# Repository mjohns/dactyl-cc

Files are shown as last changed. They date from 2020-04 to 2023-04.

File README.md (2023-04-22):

# Dactyl CC Keyboard

This keyboard and associated libraries take heavy inspiration from the
 [dactyl](https://github.com/adereth/dactyl-keyboard) and
the [dactyl_manuform](https://github.com/abstracthat/dactyl-manuform) keyboards.
 Major thanks to Matthew Adereth and Tom Short for their work.

The dactyl-cc keyboard takes a different approach to the structure of the code (and language)
 as well as being more similar in feel to the Kinesis Advantage 2.

If you are interested in a smaller version see the [mini](https://github.com/mjohns/dactyl-cc-mini) version.

If you are interested in building it you can take a look at the [guide](guide/README.md). Any dactyl build guide you choose should work like [this one.](https://medium.com/swlh/complete-idiot-guide-for-building-a-dactyl-manuform-keyboard-53454845b065)



CMake is the preferred way to build and leads to the fastest recompilation times.
```
cd build
./build.sh
```

If you do not have cmake installed you can run the simple build script which just uses g++.
```
cd build
./build_simple.sh
```

You can generate an stl from the command line with the following command:
```
cd build
// openscad -o ../things/left.stl left.scad
make_things.sh
```

The external holder cutout design is taken from https://github.com/cykedev/dactyl-cc and is designed to for loligagger's external holder.

Loligagger's external holder files:

* [Promicro V1](https://web.archive.org/web/20220607031919/https://dactyl.siskam.link/loligagger-external-holder-promicro-v1.stl)
* [Promicro V2](https://web.archive.org/web/20220607031910/https://dactyl.siskam.link/loligagger-external-holder-promicro-v2.stl)
* [Elite-C V1](https://web.archive.org/web/20220607031927/https://dactyl.siskam.link/loligagger-external-holder-elite-c-v1.stl)

v2 changes:
* Smoothed out back walls and walls around thumb cluster.
* Merged https://github.com/cykedev/dactyl-cc for external holder.
* Adjusted 'g' colum rotation from 10 to 4 degrees.

v1 stl files are archived in the things folder. The source code can be viewed on the v1 git branch.





[other images](https://imgur.com/a/jBbUXNx)

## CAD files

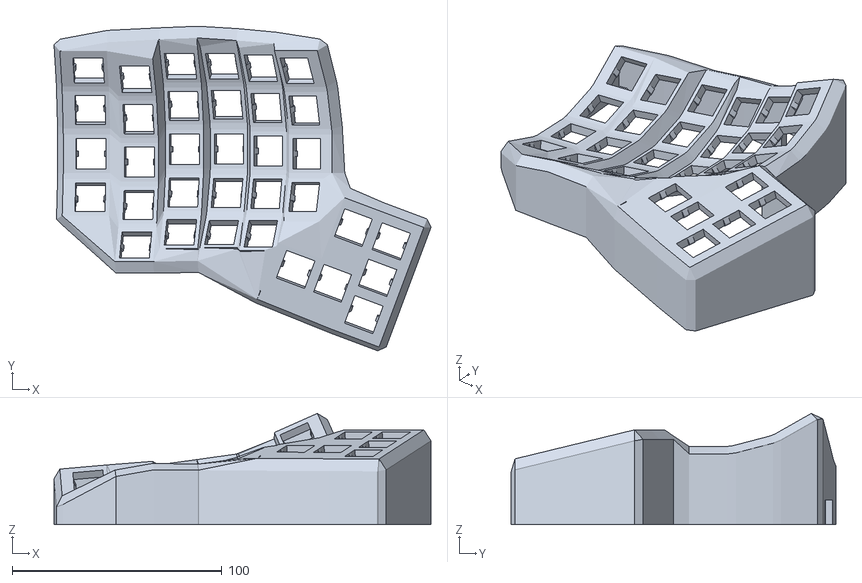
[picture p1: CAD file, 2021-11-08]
things/left.stl
179.7 x 154.7 x 53.0

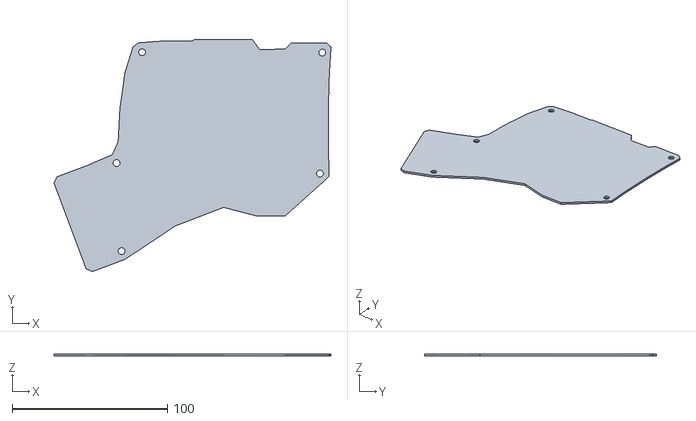
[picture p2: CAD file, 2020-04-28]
things/v1/v1_bottom_right.stl
178.4 x 149.5 x 1.50

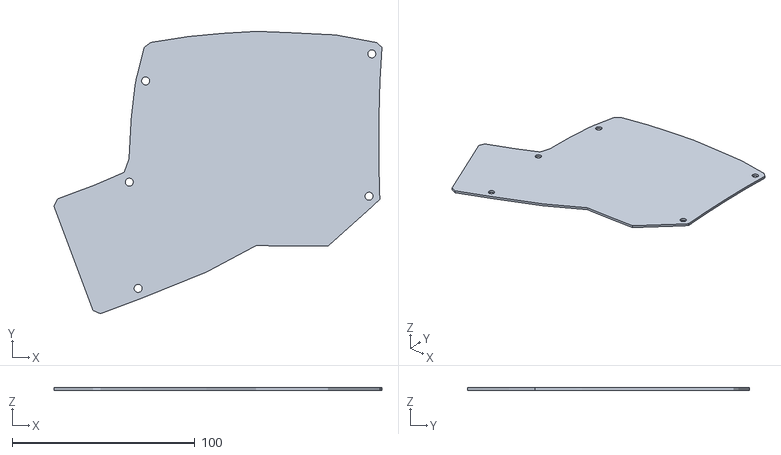
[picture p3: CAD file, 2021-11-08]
things/bottom_right.stl
179.7 x 154.7 x 1.50

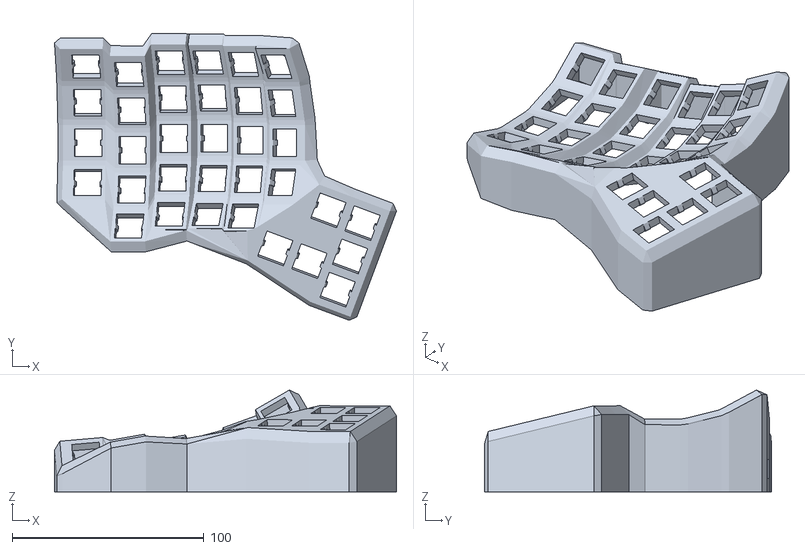
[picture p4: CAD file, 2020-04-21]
things/v1/v1_left.stl
178.4 x 149.5 x 53.2

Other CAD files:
things/v1/v1_bottom_left.stl
things/bottom_left.stl
things/right.stl
things/v1/v1_right.stl

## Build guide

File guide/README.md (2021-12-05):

I built this keyboard following the [Dactyl QMK Guide](https://www.joedevivo.com/2017-05-20-building-a-qmk-dactyl) by Joe Devivo.
 This is how I have built all of my Dactyl keyboards and allows me to build the firmware
 using the ErgodoxEZ online configurator which is now branded as [oryx](https://configure.ergodox-ez.com/).
The guide can also be found directly in the [dactyl github repo](https://github.com/adereth/dactyl-keyboard/tree/master/qmk-guide).

This keyboard does not have as much room around the keys in the corners and edges so it can be challenging to solder them.
I would suggest being mindful of what your soldering iron is touching because it is very easy to lose track and start
melting the side of the case (from personal experience). You can also solder on the diode and a stretch of wire before putting
the switch in but that turned out to be more trouble than it was worth.

The most important parts of the guide are the following two images which you will refer to quite often:
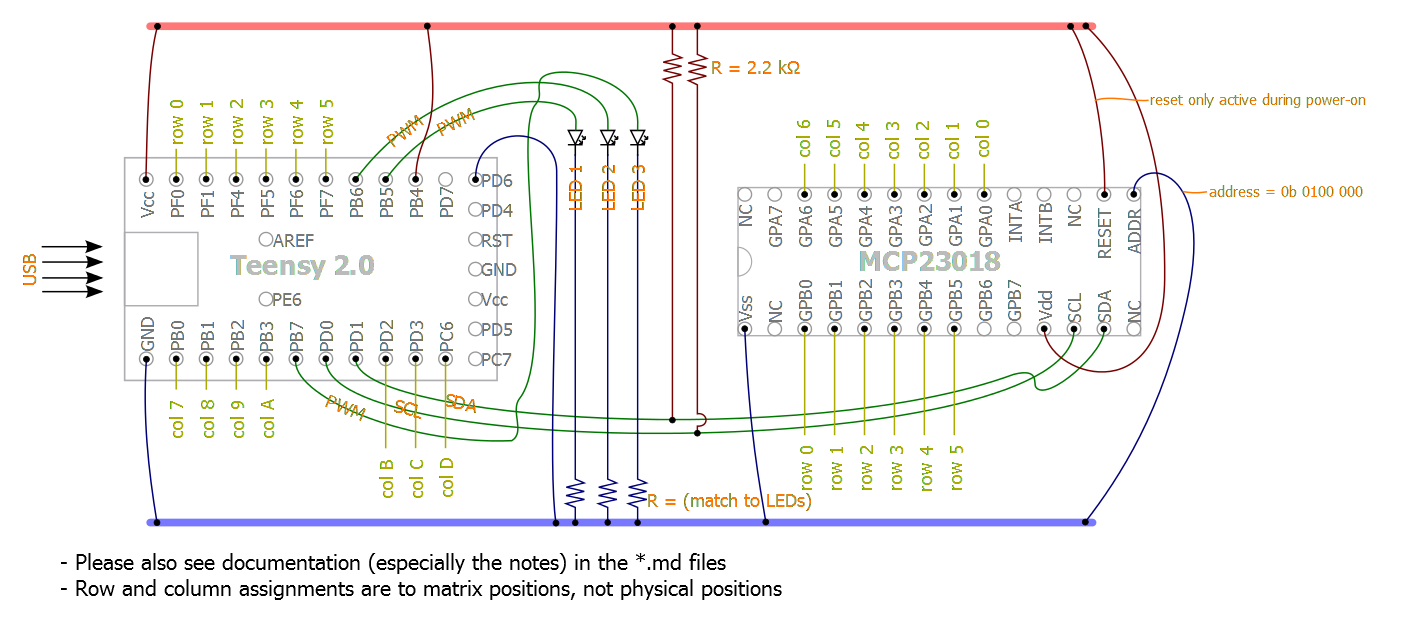
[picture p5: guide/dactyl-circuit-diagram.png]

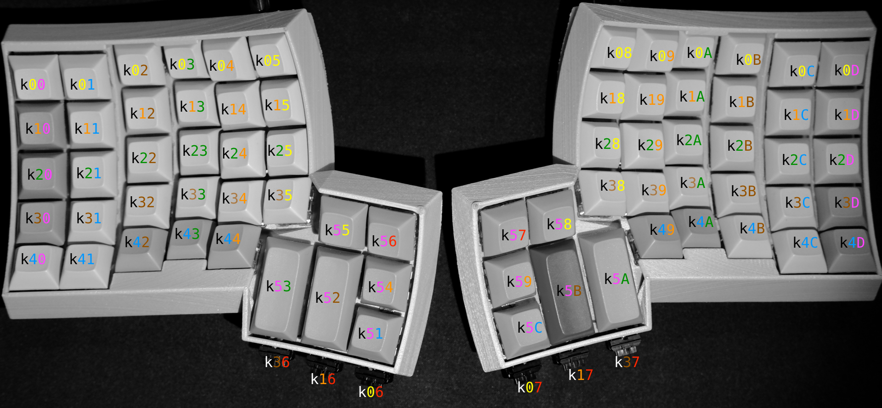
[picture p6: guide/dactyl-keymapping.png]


I think Amoeba PCBs should fit but it is a close call. I was able to get one in the tightest corner but you have to angle it very carefully to get it over the pins.



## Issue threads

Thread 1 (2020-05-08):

Bill of materials

lucasuyezu, 2020-05-08:
Congrats on the project, this is awesome!

Could you add the Bill of Materials to the README?

Thanks!

mjohns, 2020-05-09:
I added a link to the guide from the main readme. I just followed the qmk guide from the dactyl repo. https://github.com/adereth/dactyl-keyboard/tree/master/qmk-guide. I don't have a real bill or materials as a lot of the parts were left over from a dactyl build from a few years ago.

That guide has a pretty good section about the materials that you would need. If you don't want to use a Teensy (and want to use pro micros) you could look at this guide https://nickgreen.info/dactyl-manuform-build-log/.

Closed 2020-05-09.

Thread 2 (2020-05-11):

Enough space for Amoebas?

simonjohansson, 2020-05-11:
Howdie. Cool alternative to the Dactyl!

You mention in the guide,

```
This keyboard does not have as much room around the keys in the corners and edges
```

Do you think it has enough space for [Amoebas](https://keeb.io/collections/frontpage/products/amoeba-single-switch-pcbs?variant=12960782024798)?

mjohns, 2020-05-12:
I updated the guide with an image of one in the tightest corner. It fits but I don't have any experience with them to say if that is enough. See https://github.com/mjohns/dactyl-cc/tree/master/guide

simonjohansson, 2020-05-14:
Thanks!

Closed 2020-05-12.

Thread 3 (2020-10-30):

Case material

ntarocco, 2020-10-30:
Hi, thanks a lot for this repo! I am about to build my keyboard as yours! I love it.

I am still not convinced which material to use to 3d print the case. I am worried about the finishing look&feel.
Which one did you use? Are you happy with robustness and look&feel?

Maybe, it would be great to add some details about your build:
* Material: ABS, PLA or PEGT?
* Infill: 20%?
*. nice to have: any recommendation on which 3d print website to use, if you have any experience?

Thanks!

20lives, 2020-10-30:
I didn't print this variation but I have printed countless others.
Mainly the material will affect only the sturdiness of it, so any material could come out great.
Infill is also partially irrelevant since the walls are really thin.
What makes the biggest difference is the: material quality, printer quality, printer calibration, printing speed.
Moreover, there is a lot of post-processing that can be done to improve "look&feel": sanding, finishing, coating.

The best suggestion I can make is if you have the time: buy your own 3d printer and do it yourself.

mjohns, 2020-11-02:
I have printed all of my keyboards using PLA and the default Cura Ender3 profile (infill 20%). Using tree supports does save a fair bit of time and has worked well for me. I primed and spray painted (https://imgur.com/a/LsxRFcR) the keyboard which really improves the finish and I have had no problems with they keyboards over the past few years.

I printed them myself so I can't recommend any site for that.

ntarocco, 2020-11-02:
Thanks a lot for your answers! I really don't want to buy a 3d printer right now and I don't have access to any.
I have ordered online the case printed with PLA, infill 20%, black.
I was also planning to do some finishing and painting, I will post pictures when ready!

Closed 2021-11-08.

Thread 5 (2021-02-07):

Regarding similarity to Kinesis

mseflek, 2021-02-07:
Hi, Thanks for putting this together. As a long time Kinesis user I think this will solve a lot of problems I am having. Couple of quick questions:

1. Have you designed/use wrist rests with this?
2. Is the thumb cluster at the same height as it is on the Kinesis, or is it slight lower?
3. If you've used both, do you have a clear preference for this vs. the Kinesis?
4. Lastly: I noticed you reused the 1.25u keys on the pinky. Is it easy to make these 1U instead?

hasufell, 2021-06-22:
I'm also concerned about the thumb cluster, since that's one of the maon reasons to look for alternatives (they're too high).

mjohns, 2021-11-08:
1. I used a wrist pad (https://www.amazon.com/Glorious-Gaming-Wrist-Pad-Rest/dp/B0191YRMCO) on top of a 1 inch tall piece of wood. Nothing 3d printed / integrated.
2. The thumb cluster is at the same height relative to the keywell as the kinesis. The whole keyboard is slightly lower than the kinesis.
3. I prefer this over the kinesis because of QMK and the ability to adjust the position of the two keywells independently.
4. You would have to go into key_data.cc and adjust the x offset of key_caps. https://github.com/mjohns/dactyl-cc/blob/master/src/key_data.cc#L183. Changing -22.597 to something around -20.

Closed 2021-11-08.

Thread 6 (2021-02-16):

Manifold issues with the mesh

rubot42, 2021-02-16:
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
I tried editing this in FreeCAD and noticed that the mesh has some manifold errors. Here is a screenshot from Meshmixer pointing out where the errors are.

To reproduce:
- build the models with cmake (same commands as readme)
- convert to a .stl with openscad (same commands as readme)
- import stl into Meshmixer (https://www.meshmixer.com/)

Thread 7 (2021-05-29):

Stabilizers for thumb cluster

daniel2887, 2021-05-29:
Hi,

I was looking for a split keyboard that replicated the keys and layout of the Kinesis Advantage 2 and this fit the bill perfectly, so thank you for sharing your work. I'm in the process of printing it! 🤞

One question about the thumb cluster. I noticed there are no cutouts for stabilizers for the longer (2u?) keys. Did you tack those on somehow after the print? Or did you find they were not needed?

Thanks!

mjohns, 2021-05-31:
I didn't use any stabilizers and it was fine for how I type. The advantage
also doesn't have stabilizers on those thumb keys.

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

daniel2887, 2021-05-31:
Great. Thank you.

Closed 2021-05-31.

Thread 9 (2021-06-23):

Hotswap sockets

Ivche1337, 2021-06-23:
Is it possible to install [these](https://images-na.ssl-images-amazon.com/images/I/51WHrl4VGqL._AC_SX466_.jpg) hotswap sockets in this case?

kaue, 2021-10-01:
Same question :+1:

DuMaM, 2021-11-03:
Those are placed in amoeba pcb board

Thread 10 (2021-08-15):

6x6 its missing ESC and Function buttons

Nurtekin429, 2021-08-15:
I'm used to use Kinesis advantage this had the same thumb buttons.
I think its better for me then manufold.
Its great design what you have done.
I have printed left and right.
Is is possible to make 6x6. Its now missing ESC and Function buttons.
They are very useful.
Thanks in advance.

mjohns, 2021-11-08:
The esc/function keys on the kinesis are pretty different in location and sizing. It would be possible to add another row on top but it would be an involved process as this isn't a parametric layout like with the dactyl manuform. You would need to update key_data.h/cc with the new row of keys and then update the wall generating code to use those new keys instead of the existing top row.

Closed 2021-11-08.

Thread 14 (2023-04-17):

broken links in readme

EPPI-c, 2023-04-17:
links to
[pro micro v1](https://dactyl.siskam.link/loligagger-external-holder-promicro-v1.stl)
[pro micro v2](https://dactyl.siskam.link/loligagger-external-holder-promicro-v2.stl)
[elite-c](https://dactyl.siskam.link/loligagger-external-holder-elite-c-v1.stl)
are broken

Closed 2023-04-22.

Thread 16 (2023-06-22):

3D model filed corrupted

jiahuijiang, 2023-06-22:
I was trying to 3D print the base, but both v1 and v2 models are giving me warnings saying these are corrupted. Can you double check the files are uploaded correctly? Thank you!

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

guategeek, 2023-06-23:
The files are not corrupted on github, I have a copy of the repo I have been going to print from. To double check I just test downloaded the left.stl and threw in in Cura no problem. How did you download the files?

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

jiahuijiang, 2023-06-26:
@guategeek good call!
When I right-clicked on the file name and tried to directly do "save link as", the model files was shown as corrupted. But If I clicked open the file in GitHub UI and then clicked "download", that worked.
Closing this ticket out.

Closed 2023-06-26.

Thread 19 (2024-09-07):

Which keys are being used here, is it MX?

MagedEWilliam, 2024-09-07:
Noob here,
After i printed the model here, i had trouble inserting the key switches, then it dawned on me that i might have printed the wrong model or that i needed to build it with the MX type that i have.

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

My question is which key switch are being used here, and how do i get an STL with the my switch type.

MagidWilliam, 2025-03-10:
@marioolofo i tried to closely match it in cosmos, not 100% match but close enough

https://ryanis.cool/cosmos/beta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

marioolofo, 2025-03-10:
Thanks, I'll try to print this version tonight 😃

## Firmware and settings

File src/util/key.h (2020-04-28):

#pragma once

#include <functional>
#include <glm/glm.hpp>
#include <memory>
#include <string>

#include "scad.h"
#include "transform.h"

namespace scad {

// All sizes in mm.
const double kSwitchWidth = 14.4;
const double kSwitchThickness = 4;
const double kWallWidth = 2;

const double kDsaHeight = 8;
const double kSaHeight = 12.5;
// This is the height of the taller side on the key. The short side has kSaHeight.
const double kSaEdgeHeight = 13.7;
const double kDsaTopSize = 13.2;     // 0.5 * kMmPerInch;
const double kDsaBottomSize = 18.4;  // 0.725 * kMmPerInch;
// The size half way up the key used to generate the cap shape.
const double kDsaHalfSize = 16.2;
const double kSaHalfSize = 17.2;

// Size for the tall sa edged key.
const double kSaTallHeight = 14;
const double kSaTallEdgeHeight = 16.5;

const double kSwitchHorizontalOffset = kSwitchWidth / 2 + kWallWidth;

// This is the distance between the top of the switch plate and the tip of the switch stem.
const double kSwitchTipOffset = 10;

enum class KeyType {
  DSA,
  SA,            // Row 3
  SA_EDGE,       // Row 2
  SA_TALL_EDGE,  // Row 1
};
// For SA edge variants. Which side of the key the edge should be rendered.
enum class SaEdgeType { LEFT, RIGHT, TOP, BOTTOM };

struct Key {
 public:
  Key() {
  }

  Key(double x, double y, double z) {
    t().x = x;
    t().y = y;
    t().z = z;
  }

  // A name for debugging purposes. Can also be used to determine the names for key specific output
  // files.
  std::string name;

  TransformList parent_transforms;
  TransformList local_transforms;

  // These add extra width to the switch and offset the locations of the corners (GetTopLeft etc).
  double extra_width_top = 0;
  double extra_width_bottom = 0;
  double extra_width_left = 0;
  double extra_width_right = 0;

  // This makes the switch taller (moves the corner connectors down and increases wall height) while
  // leaving the top plate of the switch at the same point.
  double extra_z = 0;

  bool add_side_nub = true;
  bool disable_switch_z_offset = false;

  KeyType type = KeyType::DSA;
  SaEdgeType sa_edge_type = SaEdgeType::BOTTOM;

  void Configure(std::function<void(Key& k)> fn) {
    fn(*this);
  }

  Key& SetPosition(double x, double y, double z);
  Key& SetParent(const Key& key);
  Key& SetParent(const TransformList& transforms);

  Transform& t() {
    return local_transforms.mutable_front();
  }

  Transform& AddTransform() {
    return local_transforms.AddTransformFront();
  }

  TransformList GetTransforms() const;
  TransformList GetSwitchTransforms() const;

  Shape GetSwitch() const;
  Shape GetInverseSwitch() const;
  // Used to subtract and clear space in the key cap's path. Vertical length can be explicitly
  // passed to support cutting out for long keys like enter on the kinesis.
  Shape GetInverseCap(double custom_vertical_length = -1) const;
  Shape GetCap(bool fill_in_cap_path = false) const;

  // This is the outermost conner of the switch. You can specify an offset to scale the point back
  // by the specified x,y amount towards the center of the switch. If you had a centered 2x2 post
  // and you wanted the corner to line up with outmost point of the switch, you could specify an
  // offset of -1.
  TransformList GetTopRight(double offset = 0) const;
  TransformList GetTopLeft(double offset = 0) const;
  TransformList GetBottomRight(double offset = 0) const;
  TransformList GetBottomLeft(double offset = 0) const;
  // The same as GetSwitchTransforms but with a more clear name if you are intending to find the
  // middle point.
  TransformList GetMiddle() const;

  // Corners clockwise starting at top left. Will have size 4.
  std::vector<TransformList> GetCorners(double offset = 0) const;

 private:
  // These are the inner corners of the switch plate.
  TransformList GetTopRightInternal() const;
  TransformList GetTopLeftInternal() const;
  TransformList GetBottomRightInternal() const;
  TransformList GetBottomLeftInternal() const;
};

struct KeyGrid {
  explicit KeyGrid(std::vector<std::vector<Key*>> data) : data(std::move(data)) {
  }

  std::vector<Key*> column(int c) {
    std::vector<Key*> result;
    for (auto& row : data) {
      result.push_back(row[c]);
    }
    return result;
  }

  std::vector<Key*> row(int r) {
    return data[r];
  }

  Key* get_key(int row, int column) {
    if (row < 0 || row >= num_rows()) {
      return nullptr;
    }
    auto& r = data[row];
    if (column < 0 || column >= r.size()) {
      return nullptr;
    }
    return r[column];
  }

  std::vector<Key*> keys() {
    std::vector<Key*> result;
    for (auto& row : data) {
      for (Key* key : row) {
        if (key) {
          result.push_back(key);
        }
      }
    }
    return result;
  }

  size_t num_columns() {
    return data[0].size();
  }

  size_t num_rows() {
    return data.size();
  }

  std::vector<std::vector<Key*>> data;
};

// Used to connect key corners together. It is thin so it can have width issues when the two
// connectors being hulled don't have a large projection on one another. (keys close together with
// vertical separation)
Shape GetPostConnector();

Shape ConnectVertical(const Key& top,
                      const Key& bottom,
                      Shape connector = GetPostConnector(),
                      double offset = 0);
Shape ConnectHorizontal(const Key& left,
                        const Key& right,
                        Shape connector = GetPostConnector(),
                        double offset = 0);
Shape ConnectDiagonal(const Key& top_left,
                      const Key& top_right,
                      const Key& bottom_right,
                      const Key& bottom_left,
                      Shape connector = GetPostConnector(),
                      double offset = 0);

Shape Tri(const TransformList& t1,
          const TransformList& t2,
          const TransformList& t3,
          Shape connector = GetPostConnector());
Shape Tri(const Shape& s1, const Shape& s2, const Shape& s3);

Shape TriHull(const TransformList& t1,
              const TransformList& t2,
              const TransformList& t3,
              const TransformList& t4,
              Shape connector = GetPostConnector());
Shape TriHull(const Shape& s1, const Shape& s2, const Shape& s3, const Shape& s4);

Shape TriFan(const TransformList& center,
             const std::vector<TransformList>& transforms,
             Shape connector = GetPostConnector());
Shape TriFan(Shape center, const std::vector<Shape>& shapes);

// Makes a triangle with every consecutive set of 3 transforms. TriHull would be the same as
// calling this with 4 transforms.
Shape TriMesh(const std::vector<TransformList>& transforms, Shape connector = GetPostConnector());
Shape TriMesh(const std::vector<Shape>& shapes);
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

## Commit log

2020-04-18 add basic build instructions and check in stl
    [left.stl]
2020-04-18 move 5 out a litle more
    [left.stl]
2020-04-19 top plate looking good
2020-04-19 better adjusted wall
    [left.stl]
2020-04-19 cleaner top and wall
    [left.stl]
2020-04-20 cut out hole for cord
    [left.stl]
2020-04-20 fix position of 3 key
    [left.stl]
2020-04-20 move util files into separate dir. Fix tilde type
    [left.stl]
2020-04-21 update model
    [left.stl]
2020-04-21 add screw inserts
2020-04-21 add right, increase connector hole size
    [left.stl, right.stl]
2020-04-21 fix right
    [right.stl]
2020-04-21 update stl
    [left.stl, right.stl]
2020-04-21 add tri mesh util
    [left.stl]
2020-04-21 update right
    [right.stl]
2020-04-21 update models
    [left.stl, right.stl]
2020-04-28 bottom plate
2021-11-08 Update dactyl cc: -Merge cykedev's changes to accept external holders. -Smooth out the back wall and the wall around the thumb. -Adjust the rotation of the 'g' column to be more similar to the kinesi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
    [bottom_left.stl, bottom_right.stl, left.stl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]
